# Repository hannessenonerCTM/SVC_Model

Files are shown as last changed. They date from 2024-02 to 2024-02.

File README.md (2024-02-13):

# SVC_Model
A SVC (Static Var Compensation) model for a Educational usecase
To be used with a 110kV overhead line model operated at 1/1000 of the voltage.
Includes 3 TCC (Thyristor Controlled Capacitance) controlled via a 5V SELV control network, optionally a ATMega32U4 can be used for grid voltage regulation. A 5V PSU is included on board. There are no input filters to show the effect of a bad THDi.

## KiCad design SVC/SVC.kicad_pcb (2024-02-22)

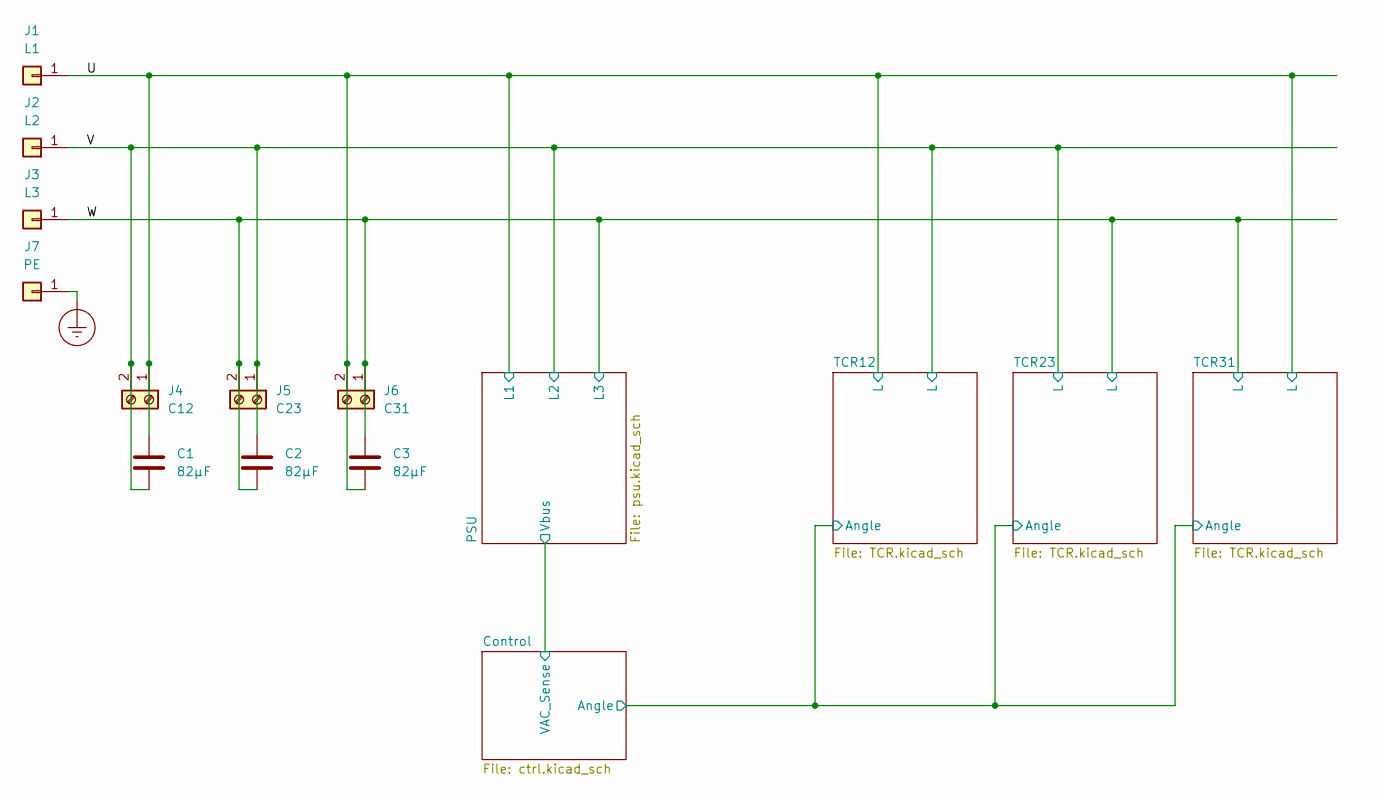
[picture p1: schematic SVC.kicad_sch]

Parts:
C1, C2, C3: 82µF
J1: L1; Banana_Jack_1Pin
J2: L2; Banana_Jack_1Pin
J3: L3; Banana_Jack_1Pin
J4: C12; TerminalBlock_bornier-2_P5.08mm
J5: C23; TerminalBlock_bornier-2_P5.08mm
J6: C31; TerminalBlock_bornier-2_P5.08mm
J7: PE; Banana_Jack_1Pin

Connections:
/U: C1.1, C3.2, J1.1, J4.1, J6.2; also elsewhere on the board
/V: C1.2, C2.1, J2.1, J4.2, J5.1; also elsewhere on the board
/W: C2.2, C3.1, J3.1, J5.2, J6.1; also elsewhere on the board
Earth_Protective: J7.1; also elsewhere on the board

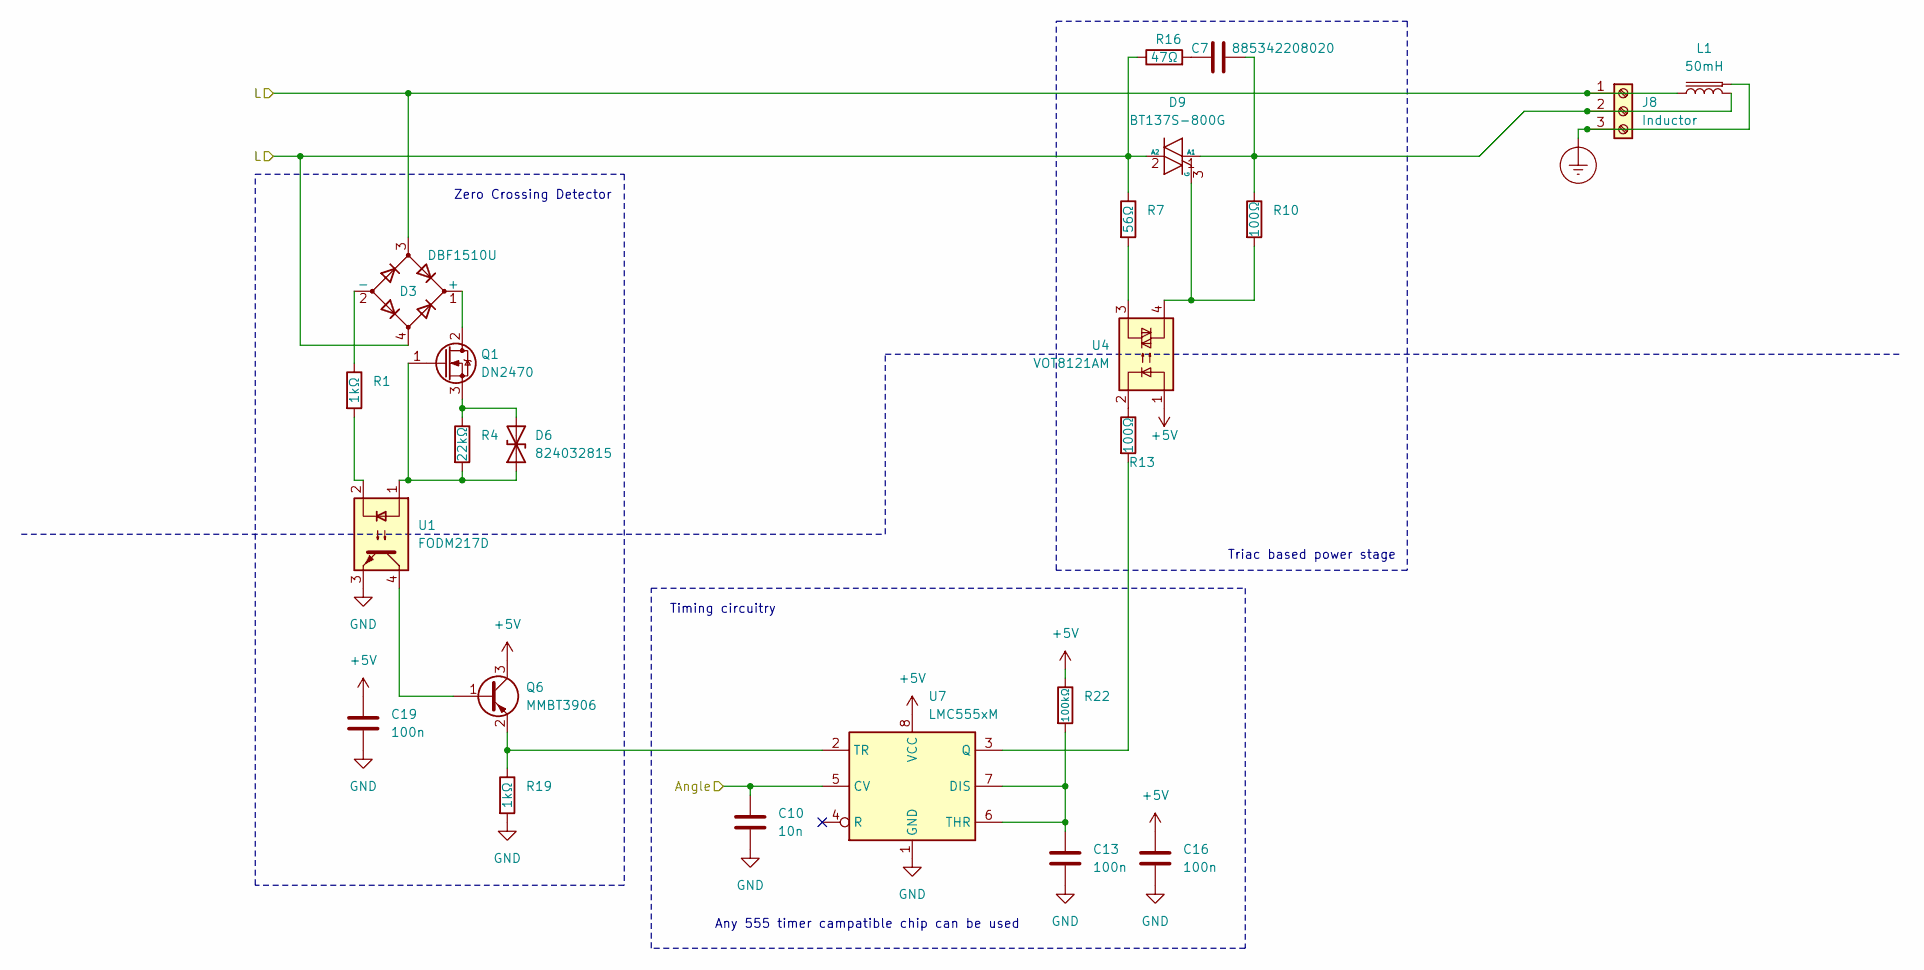
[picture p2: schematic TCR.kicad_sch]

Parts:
C7: 885342208020; C_1206_3216Metric
C10: 10n; C_0805_2012Metric
C13, C16, C19: 100n; C_0805_2012Metric
D3: DBF1510U; Diode_Bridge_Diotec_SO-DIL-Slim
D6: 824032815; TVS
D9: BT137S-800G; TO-252-2
J8: Inductor; TerminalBlock_bornier-3_P5.08mm
L1: 50mH
Q1: DN2470; TO-252-2
Q6: MMBT3906; SOT-23
R1, R19: 1kΩ; R_0805_2012Metric
R4: 22kΩ; R_0805_2012Metric
R7: 56Ω; R_1206_3216Metric
R10, R13: 100Ω; R_1206_3216Metric
R16: 47Ω; R_1210_3225Metric
R22: 100kΩ; R_0805_2012Metric
U1: FODM217D; SOP-4_4.4x2.6mm_P1.27mm
U4: VOT8121AM; SOP-4_3.8x4.1mm_P2.54mm
U7: LMC555xM; SOIC-8_3.9x4.9mm_P1.27mm

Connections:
+5V: C16.1, C19.1, Q6.3 (C), R22.1, U4.1, U7.8 (VCC); also elsewhere on the board
/Control/Angle: C10.1, U7.5 (CV); also elsewhere on the board
/U: D3.3, J8.1; also elsewhere on the board
/V: D3.4, D9.2 (A2), R7.1, R16.1; also elsewhere on the board
Earth_Protective: J8.3, L1.2; also elsewhere on the board
GND: C10.2, C13.2, C16.2, C19.2, R19.2, U1.3, U7.1 (GND); also elsewhere on the board
unnamed: C7.1, R16.2
unnamed: D3.1 (+), Q1.2 (D)
unnamed: D3.2 (-), R1.1
unnamed: D6.1 (A1), Q1.1 (G), R4.2, U1.1
unnamed: D6.2 (A2), Q1.3 (S), R4.1
unnamed: C7.2, D9.1 (A1), J8.2, R10.1
unnamed: D9.3 (G), R10.2, U4.4
unnamed: R1.2, U1.2
unnamed: R7.2, U4.3
unnamed: R13.1, U4.2
unnamed: C13.1, R22.2, U7.6 (THR), U7.7 (DIS)
unnamed: R13.2, U7.3 (Q)

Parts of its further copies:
C8, C9: 885342208020; C_1206_3216Metric
C11, C12: 10n; C_0805_2012Metric
C14, C15, C17, C18, C20, C21: 100n; C_0805_2012Metric
D4, D5: DBF1510U; Diode_Bridge_Diotec_SO-DIL-Slim
D7, D8: 824032815; TVS
D10, D11: BT137S-800G; TO-252-2
J9, J10: Inductor; TerminalBlock_bornier-3_P5.08mm
Q2, Q3: DN2470; TO-252-2
Q4, Q5: MMBT3906; SOT-23
R2, R3, R20, R21: 1kΩ; R_0805_2012Metric
R5, R6: 22kΩ; R_0805_2012Metric
R8, R9: 56Ω; R_1206_3216Metric
R11, R12, R14, R15: 100Ω; R_1206_3216Metric
R17, R18: 47Ω; R_1210_3225Metric
R23, R24: 100kΩ; R_0805_2012Metric
U2, U3: FODM217D; SOP-4_4.4x2.6mm_P1.27mm
U5, U6: VOT8121AM; SOP-4_3.8x4.1mm_P2.54mm
U8, U9: LMC555xM; SOIC-8_3.9x4.9mm_P1.27mm

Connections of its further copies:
+5V: C17.1, C18.1, C20.1, C21.1, Q4.3 (C), Q5.3 (C), R23.1, R24.1, U5.1, U6.1, U8.8 (VCC), U9.8 (VCC); also elsewhere on the board
/Control/Angle: C11.1, C12.1, U8.5 (CV), U9.5 (CV); also elsewhere on the board
/U: D5.4, D11.2 (A2), R9.1, R18.1; also elsewhere on the board
/V: D4.3, J9.1; also elsewhere on the board
/W: D4.4, D5.3, D10.2 (A2), J10.1, R8.1, R17.1; also elsewhere on the board
Earth_Protective: J9.3, J10.3; also elsewhere on the board
GND: C11.2, C12.2, C14.2, C15.2, C17.2, C18.2, C20.2, C21.2, R20.2, R21.2, U2.3, U3.3, U8.1 (GND), U9.1 (GND); also elsewhere on the board
unnamed: C8.1, R17.2
unnamed: C9.1, R18.2
unnamed: D4.1 (+), Q2.2 (D)
unnamed: D4.2 (-), R2.1
unnamed: D5.1 (+), Q3.2 (D)
unnamed: D5.2 (-), R3.1
unnamed: D7.1 (A1), Q2.1 (G), R5.2, U2.1
unnamed: D7.2 (A2), Q2.3 (S), R5.1
unnamed: D8.1 (A1), Q3.1 (G), R6.2, U3.1
unnamed: D8.2 (A2), Q3.3 (S), R6.1
unnamed: C8.2, D10.1 (A1), J9.2, R11.1
unnamed: D10.3 (G), R11.2, U5.4
unnamed: C9.2, D11.1 (A1), J10.2, R12.1
unnamed: D11.3 (G), R12.2, U6.4
unnamed: Q5.1 (B), U2.4
unnamed: Q5.2 (E), R20.1, U8.2 (TR)
unnamed: R2.2, U2.2
unnamed: R3.2, U3.2
unnamed: R8.2, U5.3
unnamed: R9.2, U6.3
unnamed: R14.1, U5.2
unnamed: R15.1, U6.2
unnamed: C14.1, R23.2, U8.6 (THR), U8.7 (DIS)
unnamed: R14.2, U8.3 (Q)
unnamed: C15.1, R24.2, U9.6 (THR), U9.7 (DIS)
unnamed: R15.2, U9.3 (Q)

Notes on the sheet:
Timing circuitry
Any 555 timer campatible chip can be used
Zero Crossing Detector
Triac based power stage

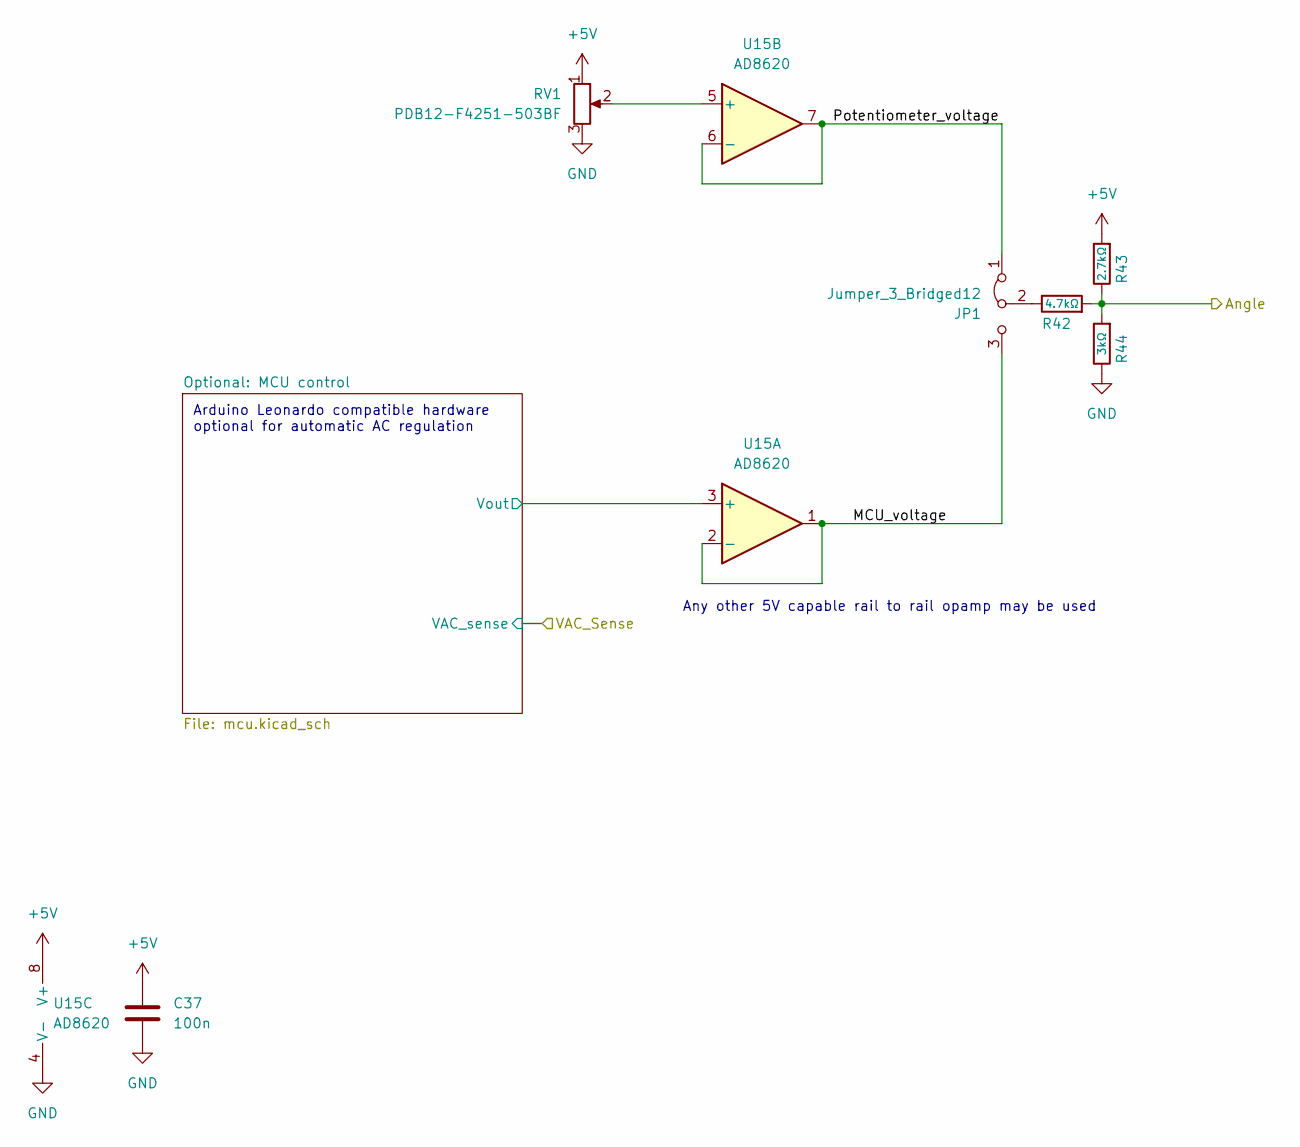
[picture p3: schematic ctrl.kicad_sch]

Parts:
C37: 100n; C_0805_2012Metric
JP1: Jumper_3_Bridged12; PinHeader_1x03_P2.54mm_Vertical
R42: 4.7kΩ; R_0805_2012Metric
R43: 2.7kΩ; R_0805_2012Metric
R44: 3kΩ; R_0805_2012Metric
RV1: PDB12-F4251-503BF; Bourns PDB12
U15: AD8620; SOIC-8_3.9x4.9mm_P1.27mm

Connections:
+5V: C37.1, R43.2, RV1.1, U15.8 (V+); also elsewhere on the board
/Control/Angle: R42.2, R43.1, R44.2; also elsewhere on the board
/Control/MCU_voltage: JP1.3 (B), U15.1, U15.2 (-)
/Control/Optional: MCU control/Vout: U15.3 (+); also elsewhere on the board
/Control/Potentiometer_voltage: JP1.1 (A), U15.6 (-), U15.7
GND: C37.2, R44.1, RV1.3, U15.4 (V-); also elsewhere on the board
unnamed: JP1.2 (C), R42.1
unnamed: RV1.2, U15.5 (+)

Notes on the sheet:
Arduino Leonardo compatible hardware optional for automatic AC regulation
Any other 5V capable rail to rail opamp may be used

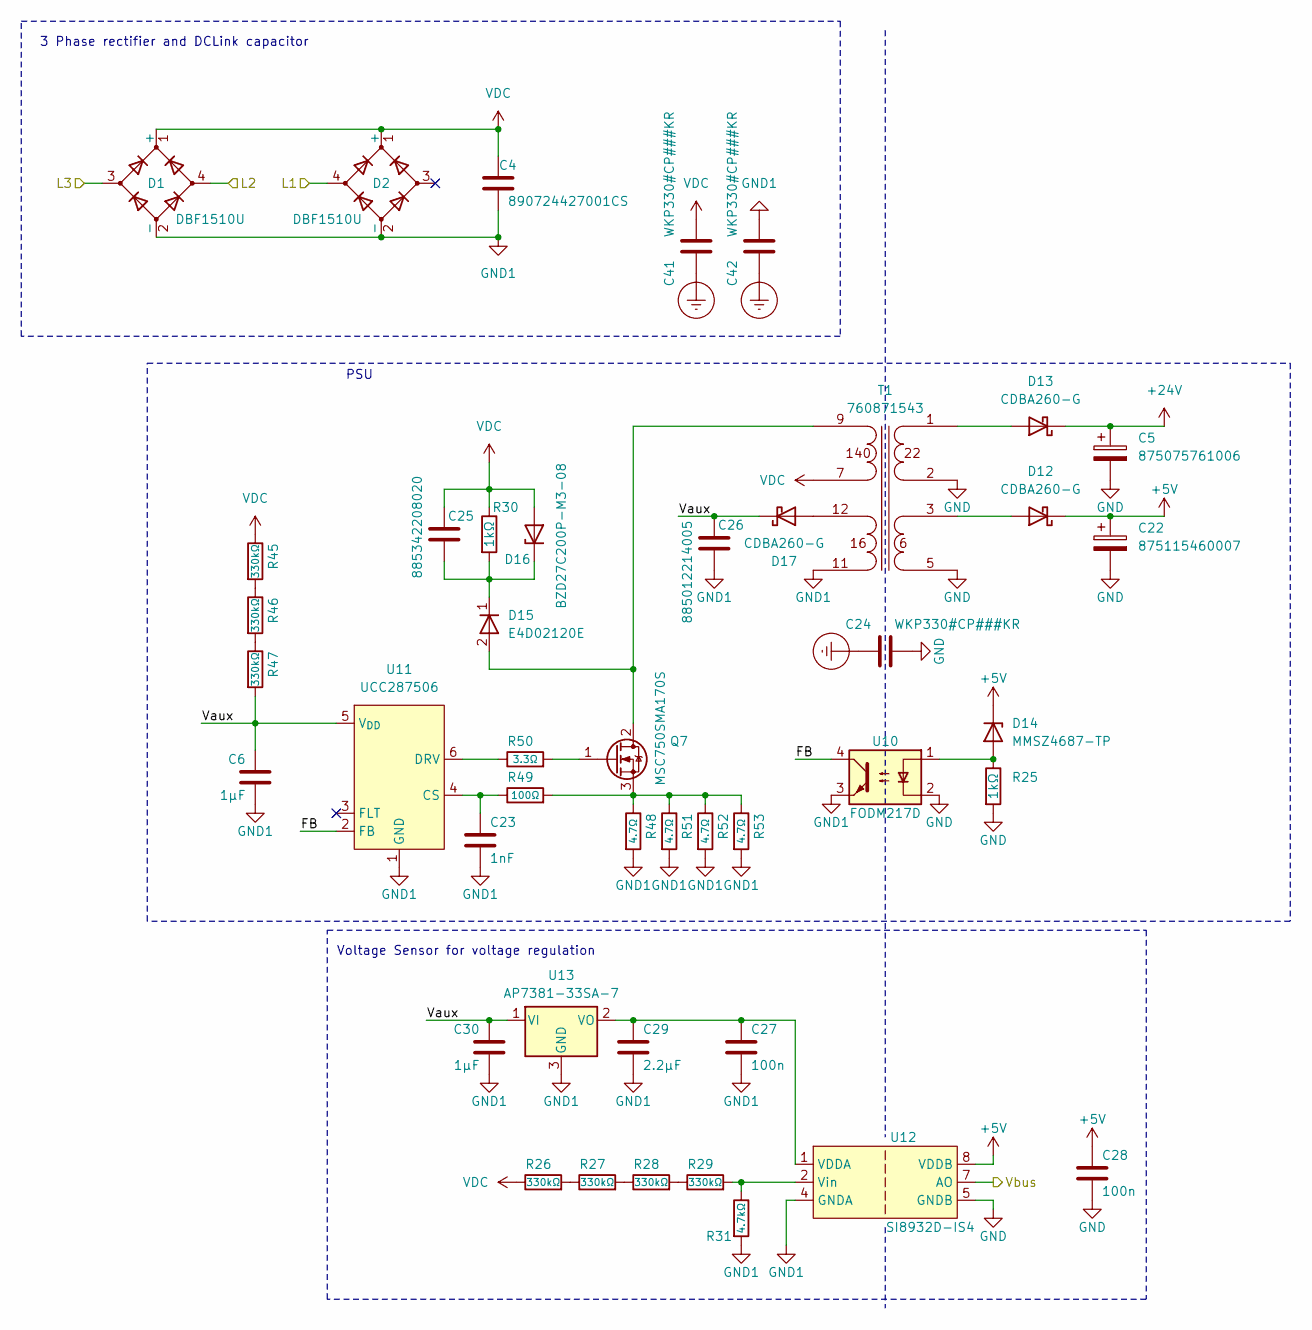
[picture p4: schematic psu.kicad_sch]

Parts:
C4: 890724427001CS; C_Rect_L31.5mm_W9.0mm_P27.50mm_MKS4
C5: 875075761006; CP_Elec_10x12.5
C6, C30: 1µF; C_0805_2012Metric
C22: 875115460007; CP_Elec_10x7.9
C23: 1nF; C_0805_2012Metric
C24, C41, C42: WKP330#CP###KR
C25: 885342208020; C_1206_3216Metric
C26: 885012214005; C_1206_3216Metric
C27, C28: 100n; C_0805_2012Metric
C29: 2.2µF; C_0805_2012Metric
D1, D2: DBF1510U; Diode_Bridge_Diotec_SO-DIL-Slim
D12, D13, D17: CDBA260-G; D_SMA
D14: MMSZ4687-TP; D_SOD-123
D15: E4D02120E; TO-252-2_TabPin1
D16: BZD27C200P-M3-08; D_SMF
Q7: MSC750SMA170S; TO-252-2
R25: 1kΩ; R_0805_2012Metric
R26, R27, R28, R29, R45, R46, R47: 330kΩ; R_0805_2012Metric
R30: 1kΩ; R_1206_3216Metric
R31: 4.7kΩ; R_0805_2012Metric
R48, R51, R52, R53: 4.7Ω; R_0805_2012Metric
R49: 100Ω; R_0805_2012Metric
R50: 3.3Ω; R_0805_2012Metric
T1: 760871543
U10: FODM217D; SOP-4_4.4x2.6mm_P1.27mm
U11: UCC287506; SOT-23-6
U12: SI8932D-IS4; SOIC-8_7.5x5.85mm_P1.27mm
U13: AP7381-33SA-7; SOT-23

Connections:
+5V: C22.1, C28.1, D12.1 (K), D14.1 (K), U12.8 (VDDB); also elsewhere on the board
+24V: C5.1, D13.1 (K); also elsewhere on the board
/Control/Optional: MCU control/Arduino Pin A0 ADC: U12.7 (AO); also elsewhere on the board
/PSU/FB: U10.4, U11.2 (FB)
/PSU/Vaux: C6.1, C26.1, C30.1, D17.1 (K), R47.2, U11.5 (V_{DD}), U13.1 (VI)
/U: D2.4; also elsewhere on the board
/V: D1.4; also elsewhere on the board
/W: D1.3; also elsewhere on the board
Earth_Protective: C24.1, C41.1, C42.1; also elsewhere on the board
GND: C5.2, C22.2, C24.2, C28.2, R25.2, T1.2 (OUT1B), T1.5 (OUT2B), T1.6 (OUT2B), U10.2, U12.5 (GNDB), U12.6 (GNDB); also elsewhere on the board
GND1: C4.2, C6.2, C23.2, C26.2, C27.2, C29.2, C30.2, C42.2, D1.2 (-), D2.2 (-), R31.2, R48.2, R51.2, R52.2, R53.2, T1.11 (IN-), U10.3, U11.1 (GND), U12.4 (GNDA), U13.3 (GND)
unnamed: D12.2 (A), T1.3 (OUT2A), T1.4 (OUT2A)
unnamed: D13.2 (A), T1.1 (OUT1A)
unnamed: D14.2 (A), R25.1, U10.1
unnamed: D15.2 (A), Q7.2 (D), T1.9 (IN+)
unnamed: C25.2, D15.1 (K), D16.1 (K), R30.2
unnamed: D17.2 (A), T1.12 (IN+)
unnamed: Q7.1 (G), R50.2
unnamed: Q7.3 (S), R48.1, R49.2, R51.1, R52.1, R53.1
unnamed: R26.2, R27.1
unnamed: R27.2, R28.1
unnamed: R28.2, R29.1
unnamed: R45.2, R46.1
unnamed: R46.2, R47.1
unnamed: C23.1, R49.1, U11.4 (CS)
unnamed: R50.1, U11.6 (DRV)
unnamed: C27.1, C29.1, U12.1 (VDDA), U13.2 (VO)
unnamed: R29.2, R31.1, U12.2 (Vin)
VDC: C4.1, C25.1, C41.2, D1.1 (+), D2.1 (+), D16.2 (A), R26.1, R30.1, R45.1, T1.7 (IN-)

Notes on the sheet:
Voltage Sensor for voltage regulation
PSU
3 Phase rectifier and DCLink capacitor

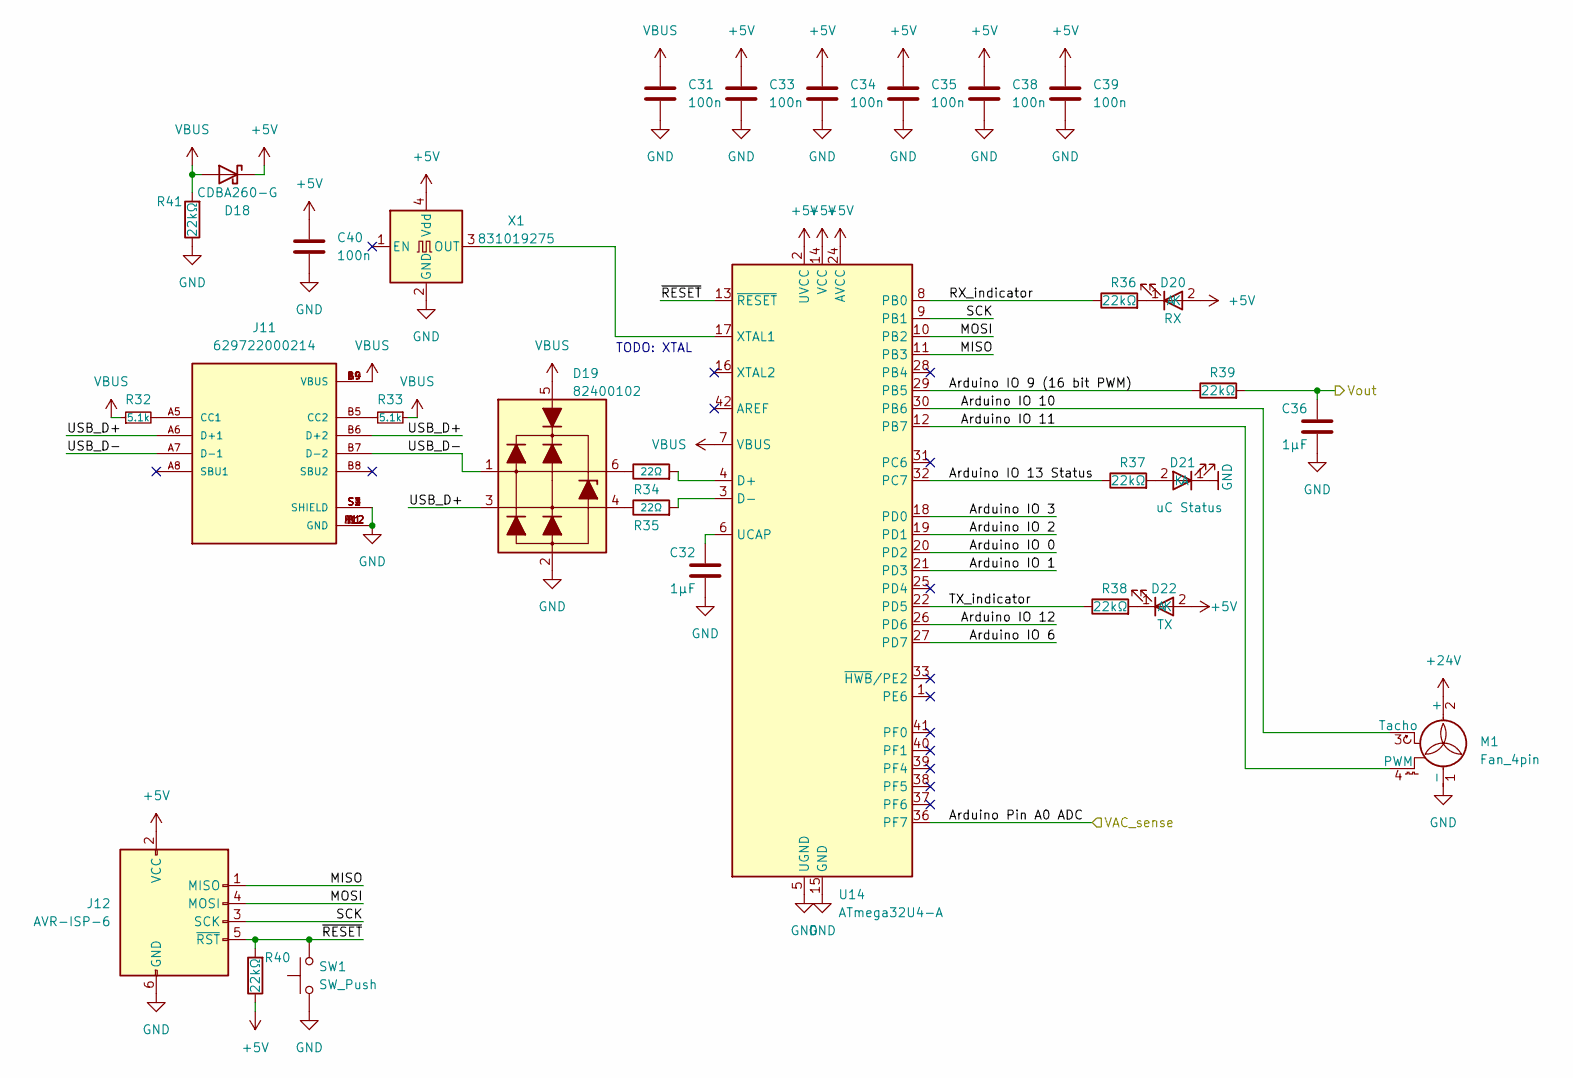
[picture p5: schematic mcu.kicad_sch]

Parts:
C31, C33, C34, C35, C38, C39, C40: 100n; C_0805_2012Metric
C32, C36: 1µF; C_0805_2012Metric
D18: CDBA260-G; D_SMA
D19: 82400102; SOT-23-6_Handsoldering
D20: RX; LED_0805_2012Metric_Pad1.15x1.40mm_HandSolder
D21: uC Status; LED_0805_2012Metric_Pad1.15x1.40mm_HandSolder
D22: TX; LED_0805_2012Metric_Pad1.15x1.40mm_HandSolder
J11: 629722000214; PARTREV 001.001
J12: AVR-ISP-6; PinHeader_2x03_P2.54mm_Vertical
M1: Fan_4pin; FanPinHeader_1x04_P2.54mm_Vertical
R32, R33: 5.1k; R_0805_2012Metric_Pad1.20x1.40mm_HandSolder
R34, R35: 22Ω; R_0805_2012Metric
R36, R37, R38, R39, R40, R41: 22kΩ; R_0805_2012Metric
SW1: SW_Push; SW_Push_1P1T_NO_6x6mm_H9.5mm
U14: ATmega32U4-A; TQFP-44_10x10mm_P0.8mm
X1: 831019275; Oscillator_SMD_Abracon_ASV-4Pin_7.0x5.1mm

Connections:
+5V: C33.1, C34.1, C35.1, C38.1, C39.1, C40.1, D18.1 (K), D20.2 (A), D22.2 (A), J12.2 (VCC), R40.1, U14.2 (UVCC), U14.14 (VCC), U14.24 (AVCC), U14.34 (VCC), U14.44 (AVCC), X1.4 (Vdd); also elsewhere on the board
+24V: M1.2 (+); also elsewhere on the board
/Control/Optional: MCU control/Arduino IO 0: U14.20 (PD2)
/Control/Optional: MCU control/Arduino IO 1: U14.21 (PD3)
/Control/Optional: MCU control/Arduino IO 2: U14.19 (PD1)
/Control/Optional: MCU control/Arduino IO 3: U14.18 (PD0)
/Control/Optional: MCU control/Arduino IO 6: U14.27 (PD7)
/Control/Optional: MCU control/Arduino IO 9 (16 bit PWM): R39.1, U14.29 (PB5)
/Control/Optional: MCU control/Arduino IO 10: M1.3 (Tacho), U14.30 (PB6)
/Control/Optional: MCU control/Arduino IO 11: M1.4 (PWM), U14.12 (PB7)
/Control/Optional: MCU control/Arduino IO 12: U14.26 (PD6)
/Control/Optional: MCU control/Arduino IO 13 Status: R37.1, U14.32 (PC7)
/Control/Optional: MCU control/Arduino Pin A0 ADC: U14.36 (PF7); also elsewhere on the board
/Control/Optional: MCU control/MISO: J12.1 (MISO), U14.11 (PB3)
/Control/Optional: MCU control/MOSI: J12.4 (MOSI), U14.10 (PB2)
/Control/Optional: MCU control/RX_indicator: R36.1, U14.8 (PB0)
/Control/Optional: MCU control/SCK: J12.3 (SCK), U14.9 (PB1)
/Control/Optional: MCU control/TX_indicator: R38.1, U14.22 (PD5)
/Control/Optional: MCU control/USB_D+: D19.3 (L2), J11.A6 (D+1), J11.B6 (D+2)
/Control/Optional: MCU control/USB_D-: D19.1 (L1), J11.A7 (D-1), J11.B7 (D-2)
/Control/Optional: MCU control/Vout: C36.1, R39.2; also elsewhere on the board
/Control/Optional: MCU control/~RESET: J12.5 (~RST), R40.2, SW1.2, U14.13 (~RESET)
GND: C31.2, C32.2, C33.2, C34.2, C35.2, C36.2, C38.2, C39.2, C40.2, D19.2 (VN), D21.1 (K), J11.A1 (GND), J11.A12 (GND), J11.B1 (GND), J11.B12 (GND), J11.S1 (SHIELD), J11.S2 (SHIELD), J11.S3 (SHIELD), J11.S4 (SHIELD), J12.6 (GND), M1.1 (-), R41.1, SW1.1, U14.5 (UGND), U14.15 (GND), U14.23 (GND), U14.35 (GND), U14.43 (GND), X1.2 (GND); also elsewhere on the board
unnamed: D19.6 (L1), R34.1
unnamed: D19.4 (L2), R35.1
unnamed: D20.1 (K), R36.2
unnamed: D21.2 (A), R37.2
unnamed: D22.1 (K), R38.2
unnamed: J11.A5 (CC1), R32.2
unnamed: J11.B5 (CC2), R33.2
unnamed: R34.2, U14.4 (D+)
unnamed: R35.2, U14.3 (D-)
unnamed: C32.1, U14.6 (UCAP)
unnamed: U14.17 (XTAL1), X1.3 (OUT)
VBUS: C31.1, D18.2 (A), D19.5 (VP), J11.A4 (VBUS), J11.A9 (VBUS), J11.B4 (VBUS), J11.B9 (VBUS), R32.1, R33.1, R41.2, U14.7 (VBUS)

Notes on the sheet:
TODO: XTAL

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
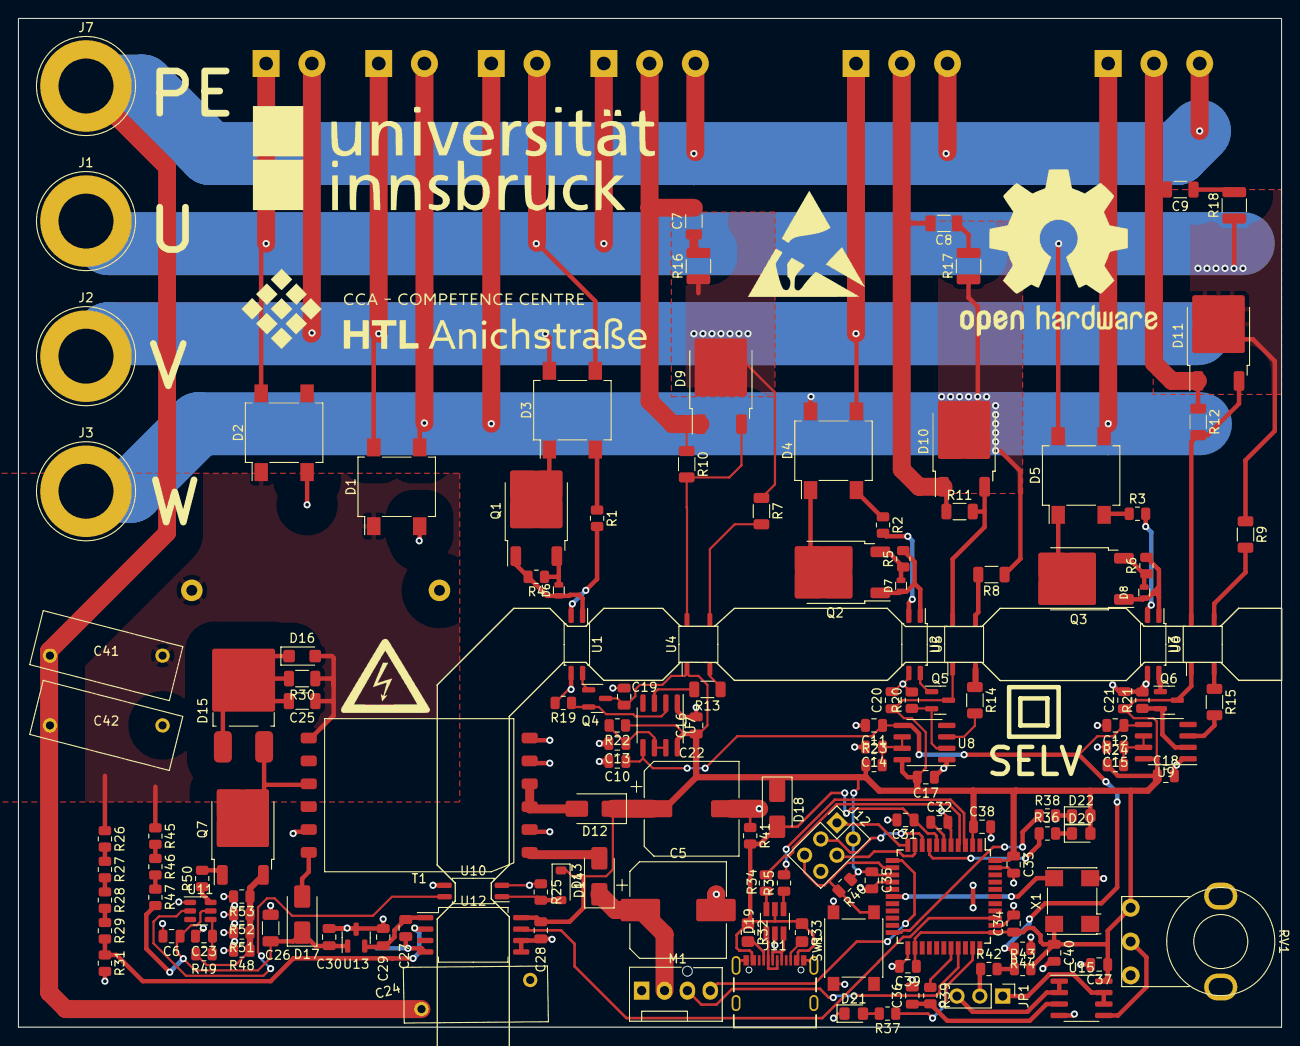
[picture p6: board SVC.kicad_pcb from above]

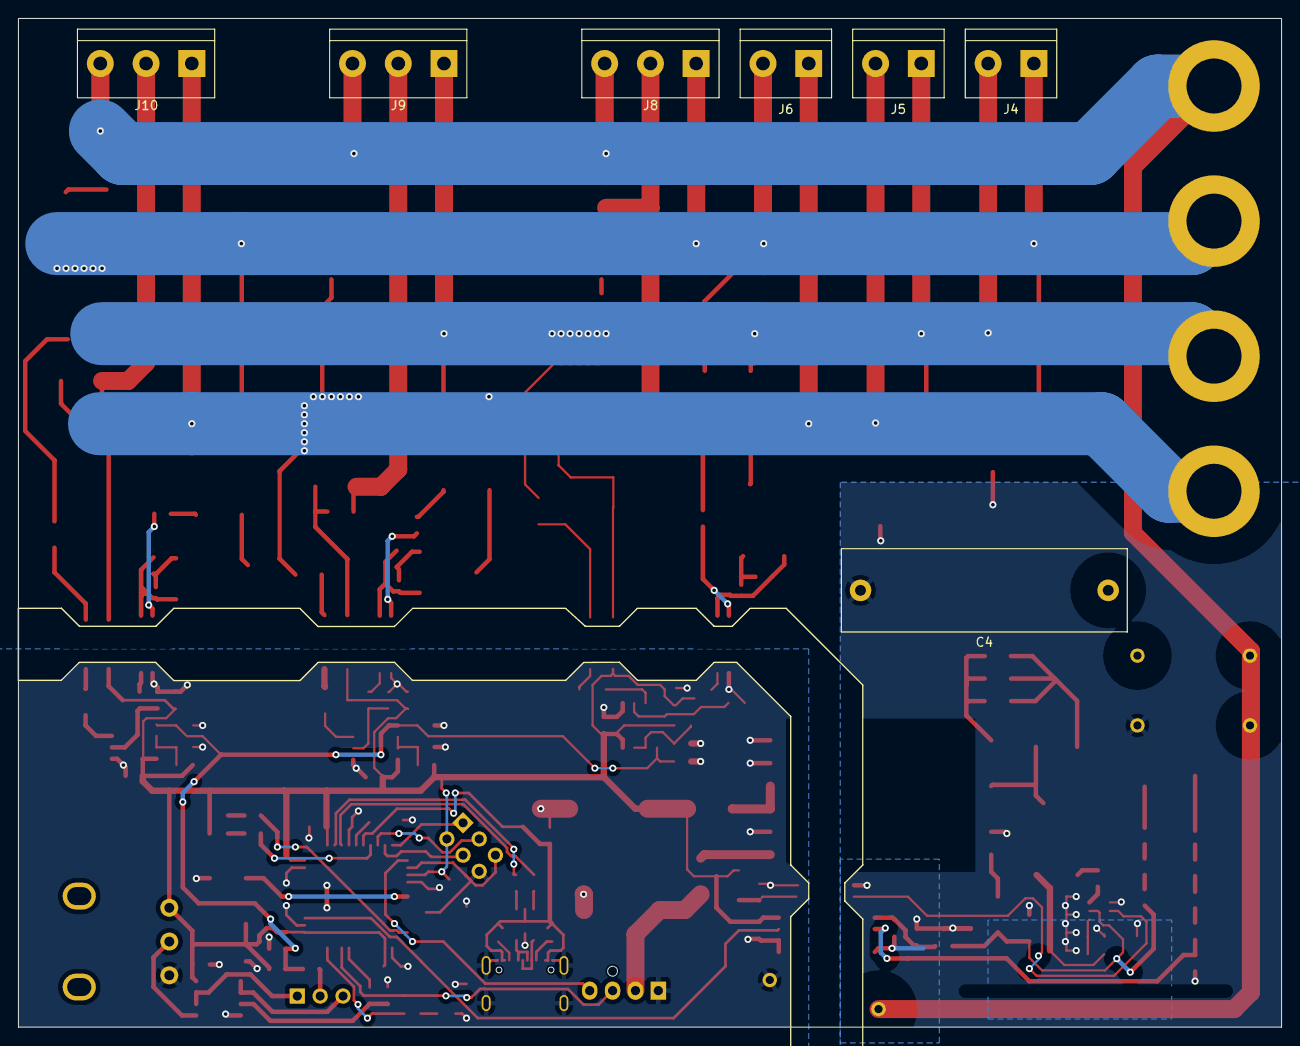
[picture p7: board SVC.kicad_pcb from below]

Board: 2 copper layers, 140.2 x 112.0 mm, 154 parts (7 on the bottom side), 101 nets.

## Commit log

2024-02-14 Added simulation model, drawn schematic
    [SVC.kicad_pcb, SVC.kicad_sch, TCR.kicad_sch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]
2024-02-21 did some layout work, minor schematic changes to help with layout
    [SVC.kicad_pcb, SVC.kicad_sch, TCR.kicad_sch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]
2024-02-22 added some symbols, marked LV area as SELV
    [SVC.kicad_pcb]
